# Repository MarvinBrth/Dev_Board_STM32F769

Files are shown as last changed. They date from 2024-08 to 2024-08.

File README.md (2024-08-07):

# Dev_Board_STM32F769
## Feature
- STM32F769BIT6
- OTG USB C FS
- OTG USB C HS
- DRAM
- DSI_Interface
- EMMC
### Infos
- Created with Kicad
- 6 Layer
- 5 x 5 cm
- Manufactorer: JLCPCB
- PCBA
  
## Blockdiagramm:



## Supply:



## STM32F769BIT6:



## USB_C_FS_OTG:



## USB_C_HS_OTG:



## EMMC:



## DSI_Interface:



## SDRAM:



## Layout:



## 3D-Model:



## Real life

dev_board

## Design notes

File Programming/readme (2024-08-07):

Can be programmed via the Tag-Connector using the STM32CubeIDE.
https://www.st.com/en/development-tools/stm32cubeide.html

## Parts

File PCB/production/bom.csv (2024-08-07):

Designator | Footprint | Quantity | Value | LCSC Part #
C1, C2, C35, C37, C44, C49 | 0603 | 6 | 1uF
C10 | 0805 | 1 | 22uF
C11, C12, C3, C4, C7, C8 | 0805 | 6 | 4.7uF
C13, C14, C15, C16, C17, C18, C19, C20, C21, C22, C23, C24, C25, C26, C27, C28, C30, C31, C34, C36, C41, C46, C47, C50, C51, C54, C56, C59, C61, C64, C66, C68, C69, C70, C71, C72, C74, C75, C76 | 0402 | 39 | 100nF
C29, C32, C33, C67 | 0603 | 4 | 4.7uF
C38, C42, C43, C73, C77 | 0603 | 5 | 2.2uF
C39, C40, C57, C58 | 0402 | 4 | 10pF
C45, C55 | 0603 | 2 | 5.6uF
C48, C60 | 0805 | 2 | 100uF
C5, C6, C9 | 0805 | 3 | 10uF
C52 | 0402 | 1 | 2.2uF
C53, C62, C65 | 0402 | 3 | 4.7uF
C63 | 0402 | 1 | 1uF
D1, D2, D3 | BAT165 | 3 | BAT165
D4, D5, D6, D7, D8, D9 | 0603 | 6 | LED
FB1, FB2, FB3, FB4 | 0603 | 4 | FerriteBead
J1 | JST_XH_B2B-XH-A_1x02_P2.50mm_Vertical | 1 | Conn_01x02
J3, J4 | GT-USB-7047B_JLCPCB | 2 | USB_C_Receptacle_USB2.0_16P
J5 | TE_1-84952-5_1x15-1MP_P1.0mm_Horizontal | 1 | Conn_01x15
R1, R13, R15, R2, R22, R24, R25, R3 | 0402 | 8 | 10kR
R10, R16 | 0402 | 2 | 3k3R
R11, R17 | 0402 | 2 | 430kR
R12, R18 | 0402 | 2 | 620kR
R14, R23 | 0402 | 2 | 900kR
R19 | 0402 | 1 | 20kR
R20 | 0402 | 1 | 1MR
R21 | 0402 | 1 | 8.06kR 1%
R26, R27 | Widerstandsarray_1 | 2 | 10kR
R28, R29 | 0402 | 2 | 1.5kR
R4 | 0402 | 1 | 5kR
R5, R8 | 0402 | 2 | 330R
R6, R7, R9 | 0402 | 3 | 1kR
U1 | SOT-23 | 1 | MCP1700x-180xxTT
U10, U6 | SOT-23-6 | 2 | USBLC6-2SC6
U11, U7 | TUSB321RWBR | 2 | TUSB321RWBR
U12 | EMMC | 1 | EMMC64G-IY29-5B101
U13 | TSOP-II-54_22.2x10.16mm_P0.8mm | 1 | IS42S16400J-7TL
U2 | SOT-223-3_TabPin2 | 1 | AMS1117-5.0
U3 | SOT-223-3_TabPin2 | 1 | AMS1117-3.3
U4 | LQFP-208_28x28mm_P0.5mm | 1 | STM32F769BIT6
U5, U8 | STMPS | 2 | STMPS2151STR
U9 | USB_ULPI | 1 | USB3320C-EZK-TR
Y1 | XTAL_ECS-240-10-36-CKM-TR | 1 | 26MHz
Y2 | XTAL_ECS-240-10-36-CKM-TR | 1 | 24MHz

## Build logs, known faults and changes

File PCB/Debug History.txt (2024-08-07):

18.05.24:
1. 9V to GND	/	5V to GND	/	3V3 to GND	/ 	1V8 to GND;
		Kein Kurzschluss

2. 9V angeschlossen und diverse Spannungen gechecked;
		PASS

3. Spannungen über LED´s gemessen;
		*Ist = 2,6V, Soll = 2,6V*
	
4. _test_

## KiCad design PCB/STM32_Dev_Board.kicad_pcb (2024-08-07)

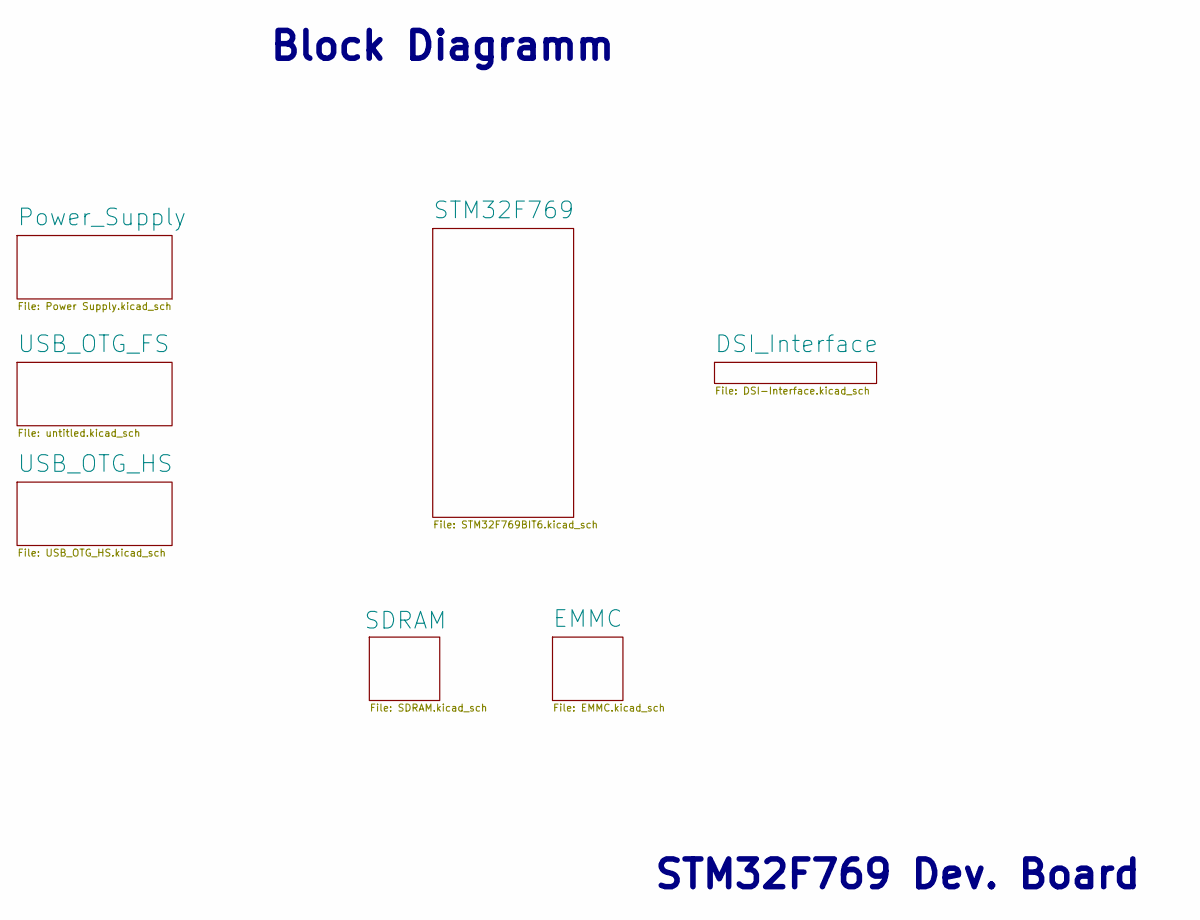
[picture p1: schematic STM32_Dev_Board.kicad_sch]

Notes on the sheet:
STM32F769 Dev. Board
Block Diagramm

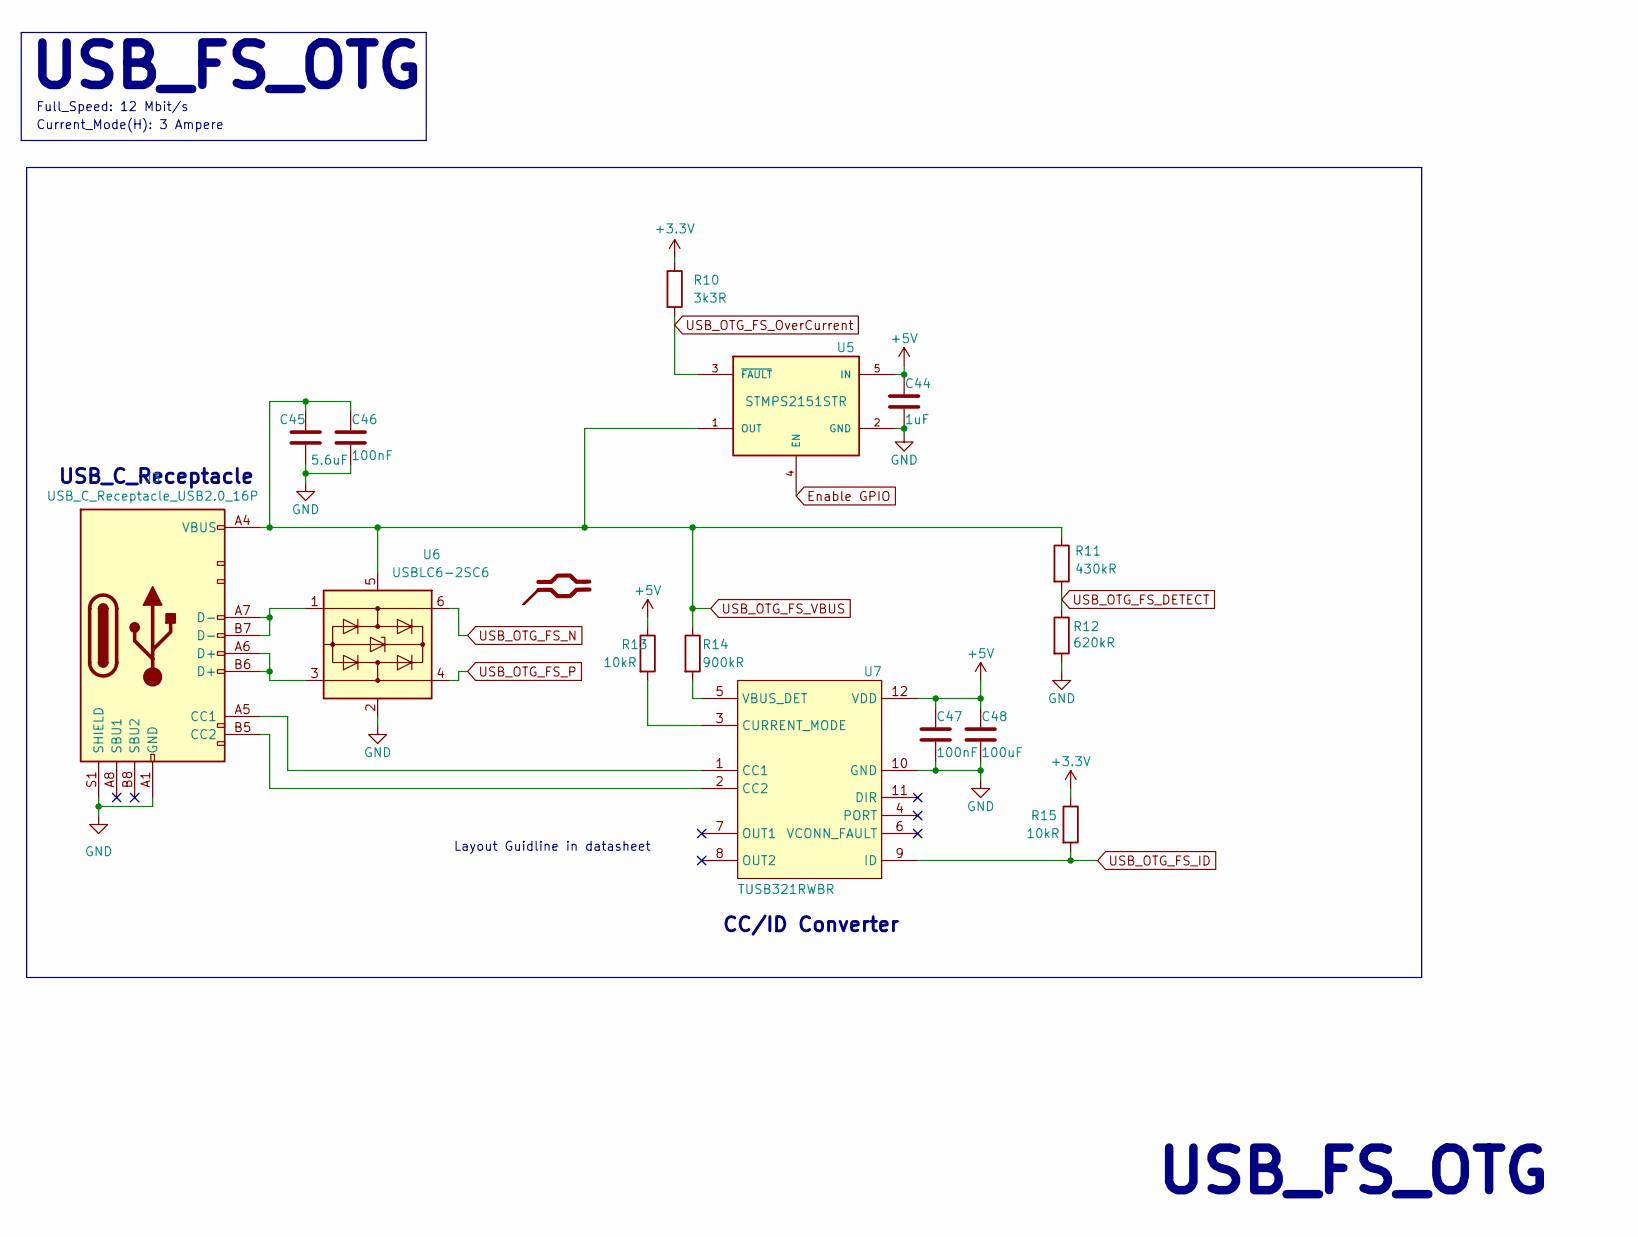
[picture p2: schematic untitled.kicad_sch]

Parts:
C44: 1uF; C_0603_1608Metric
C45: 5.6uF; C_0603_1608Metric
C46, C47: 100nF; C_0402_1005Metric
C48: 100uF; C_0805_2012Metric
J3: USB_C_Receptacle_USB2.0_16P; GT-USB-7047B_JLCPCB
R10: 3k3R; R_0402_1005Metric
R11: 430kR; R_0402_1005Metric
R12: 620kR; R_0402_1005Metric
R13, R15: 10kR; R_0402_1005Metric
R14: 900kR; R_0402_1005Metric
U5: STMPS2151STR; STMPS; PARTREV 7
U6: USBLC6-2SC6; SOT-23-6
U7: TUSB321RWBR

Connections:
+5V: C44.1, C47.1, C48.1, R13.1, U5.5 (IN), U7.12 (VDD); also elsewhere on the board
Enable GPIO: U5.4 (EN); also elsewhere on the board
GND: C44.2, C45.2, C46.2, C47.2, C48.2, J3.A1 (GND), J3.A12 (GND), J3.B1 (GND), J3.B12 (GND), J3.S1 (SHIELD), R12.2, U5.2 (GND), U6.2 (GND), U7.10 (GND); also elsewhere on the board
unnamed: J3.A5 (CC1), U7.1 (CC1)
unnamed: J3.B5 (CC2), U7.2 (CC2)
unnamed: J3.A6 (D+), J3.B6 (D+), U6.3 (I/O2)
unnamed: J3.A7 (D-), J3.B7 (D-), U6.1 (I/O1)
unnamed: R13.2, U7.3 (CURRENT_MODE)
unnamed: R14.2, U7.5 (VBUS_DET)
USB_OTG_FS_DETECT: R11.2, R12.1; also elsewhere on the board
USB_OTG_FS_ID: R15.2, U7.9 (ID); also elsewhere on the board
USB_OTG_FS_N: U6.6 (I/O1); also elsewhere on the board
USB_OTG_FS_OverCurrent: R10.2, U5.3 (~FAULT); also elsewhere on the board
USB_OTG_FS_P: U6.4 (I/O2); also elsewhere on the board
USB_OTG_FS_VBUS: C45.1, C46.1, J3.A4 (VBUS), J3.A9 (VBUS), J3.B4 (VBUS), J3.B9 (VBUS), R11.1, R14.1, U5.1 (OUT), U6.5 (VBUS); also elsewhere on the board
VDDSDMMC_STM32: R10.1, R15.1; also elsewhere on the board

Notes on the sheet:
Full_Speed: 12 Mbit/s
USB_FS_OTG
CC/ID Converter
Current_Mode(H): 3 Ampere
USB_C_Receptacle
Layout Guidline in datasheet

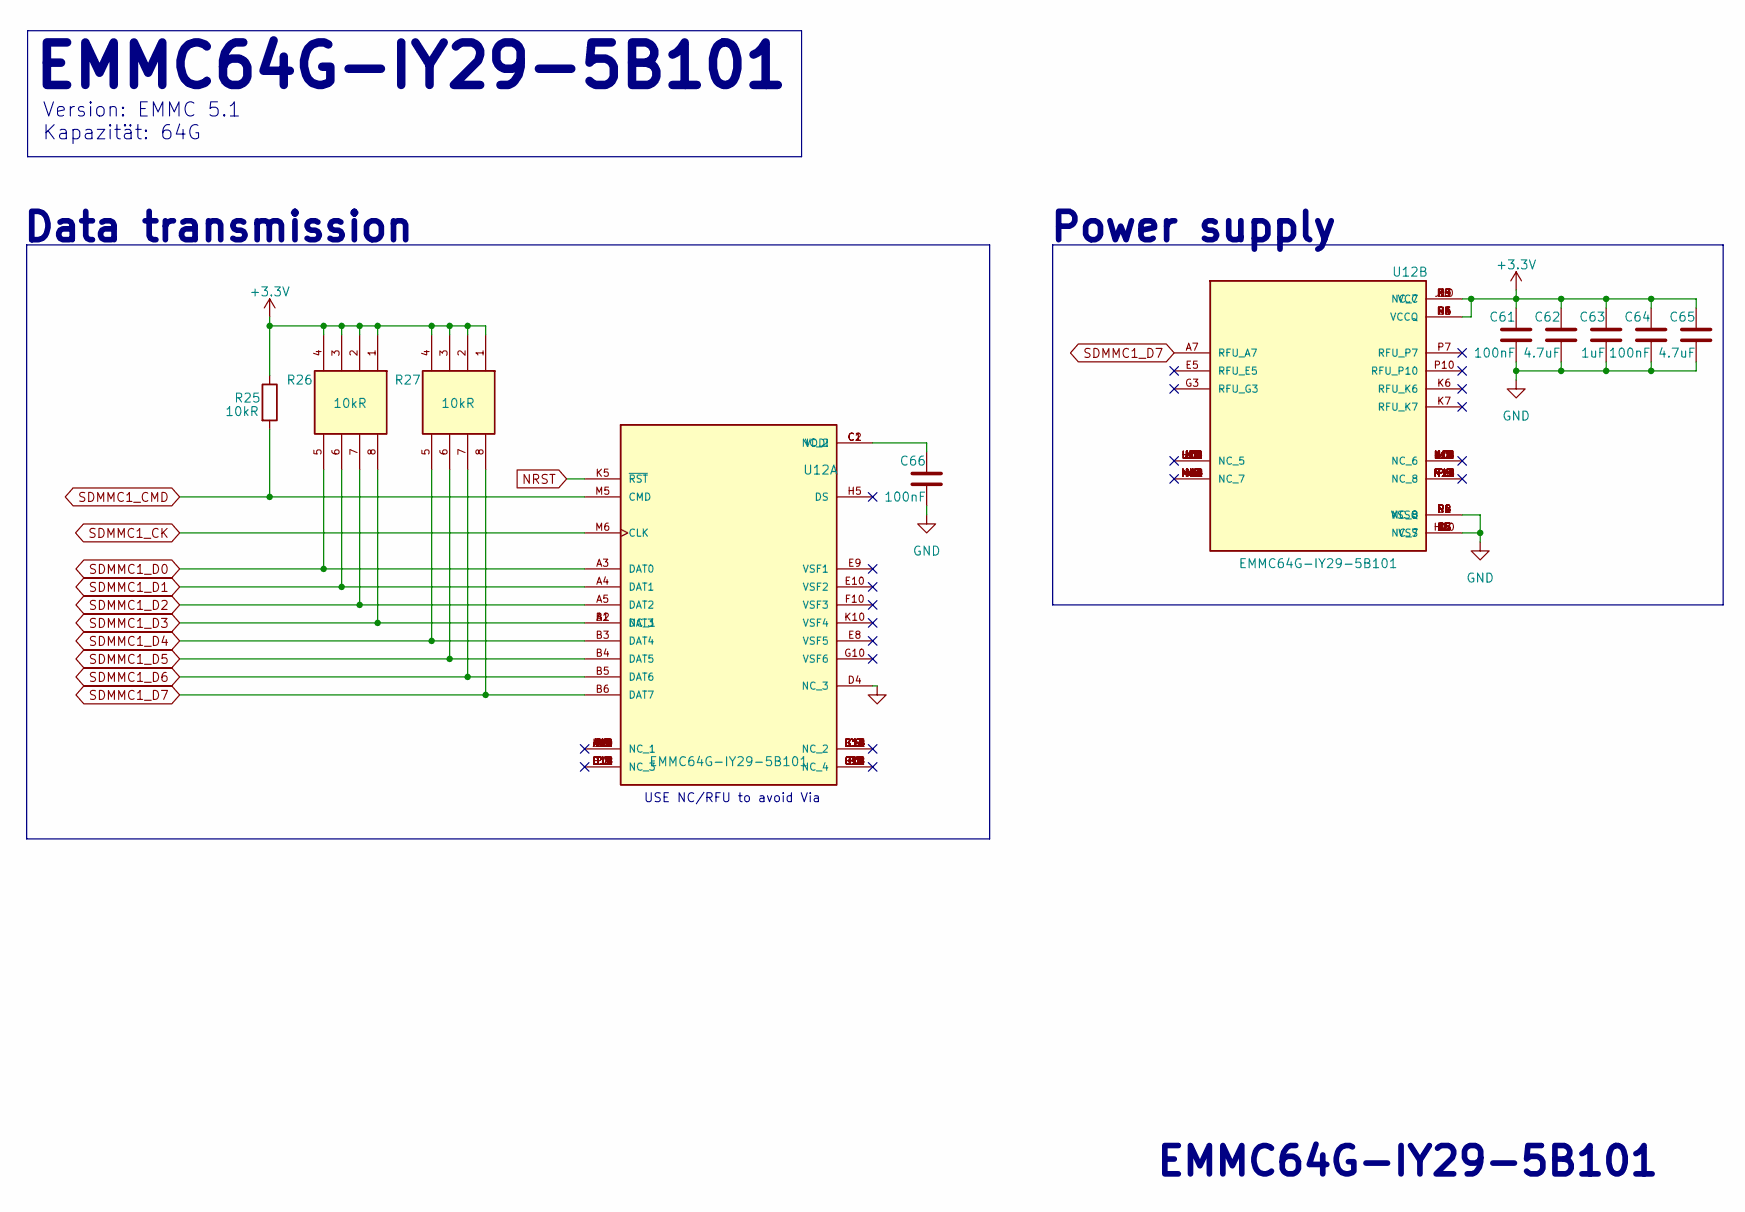
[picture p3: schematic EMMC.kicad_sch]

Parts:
C61, C64, C66: 100nF; C_0402_1005Metric
C62, C65: 4.7uF; C_0402_1005Metric
C63: 1uF; C_0402_1005Metric
R25: 10kR; R_0402_1005Metric
R26, R27: 10kR; Widerstandsarray_1; PARTREV 1-Mar-20
U12: EMMC64G-IY29-5B101; EMMC; PARTREV N/A

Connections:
GND: C61.2, C62.2, C63.2, C64.2, C65.2, C66.2, U12.A6 (VSS), U12.C4 (VSSQ), U12.D4 (NC_3), U12.E7 (VSS), U12.G5 (VSS), U12.H10 (VSS), U12.J5 (VSS), U12.K8 (VSS), U12.N2 (VSSQ), U12.N5 (VSSQ), U12.N6 (NC_7), U12.P2 (NC_8), U12.P4 (VSSQ), U12.P6 (VSSQ); also elsewhere on the board
NRST: U12.K5 (~RST); also elsewhere on the board
unnamed: C66.1, U12.C1 (NC_2), U12.C2 (VDDI)
SDMMC1_CK: U12.M6 (CLK); also elsewhere on the board
SDMMC1_CMD: R25.2, U12.M5 (CMD); also elsewhere on the board
SDMMC1_D0: R26.5, U12.A3 (DAT0); also elsewhere on the board
SDMMC1_D1: R26.6, U12.A4 (DAT1); also elsewhere on the board
SDMMC1_D2: R26.7, U12.A5 (DAT2); also elsewhere on the board
SDMMC1_D3: R26.8, U12.A1 (NC_1), U12.B2 (DAT3); also elsewhere on the board
SDMMC1_D4: R27.5, U12.A2 (NC_1), U12.B3 (DAT4); also elsewhere on the board
SDMMC1_D5: R27.6, U12.B4 (DAT5), U12.C3 (NC_2), U12.D1 (NC_3), U12.D2 (NC_3), U12.D3 (NC_3); also elsewhere on the board
SDMMC1_D6: R27.7, U12.B5 (DAT6), U12.C5 (NC_2); also elsewhere on the board
SDMMC1_D7: R27.8, U12.A7 (RFU_A7), U12.B6 (DAT7); also elsewhere on the board
VDDSDMMC_STM32: C61.1, C62.1, C63.1, C64.1, C65.1, R25.1, R26.1, R26.2, R26.3, R26.4, R27.1, R27.2, R27.3, R27.4, U12.C6 (VCCQ), U12.E6 (VCC), U12.F5 (VCC), U12.J10 (VCC), U12.K9 (VCC), U12.M4 (VCCQ), U12.N3 (NC_7), U12.N4 (VCCQ), U12.P3 (VCCQ), U12.P5 (VCCQ); also elsewhere on the board

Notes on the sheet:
USE NC/RFU to avoid Via
Data transmission
EMMC64G-IY29-5B101
Version: EMMC 5.1 Kapazität: 64G
Power supply

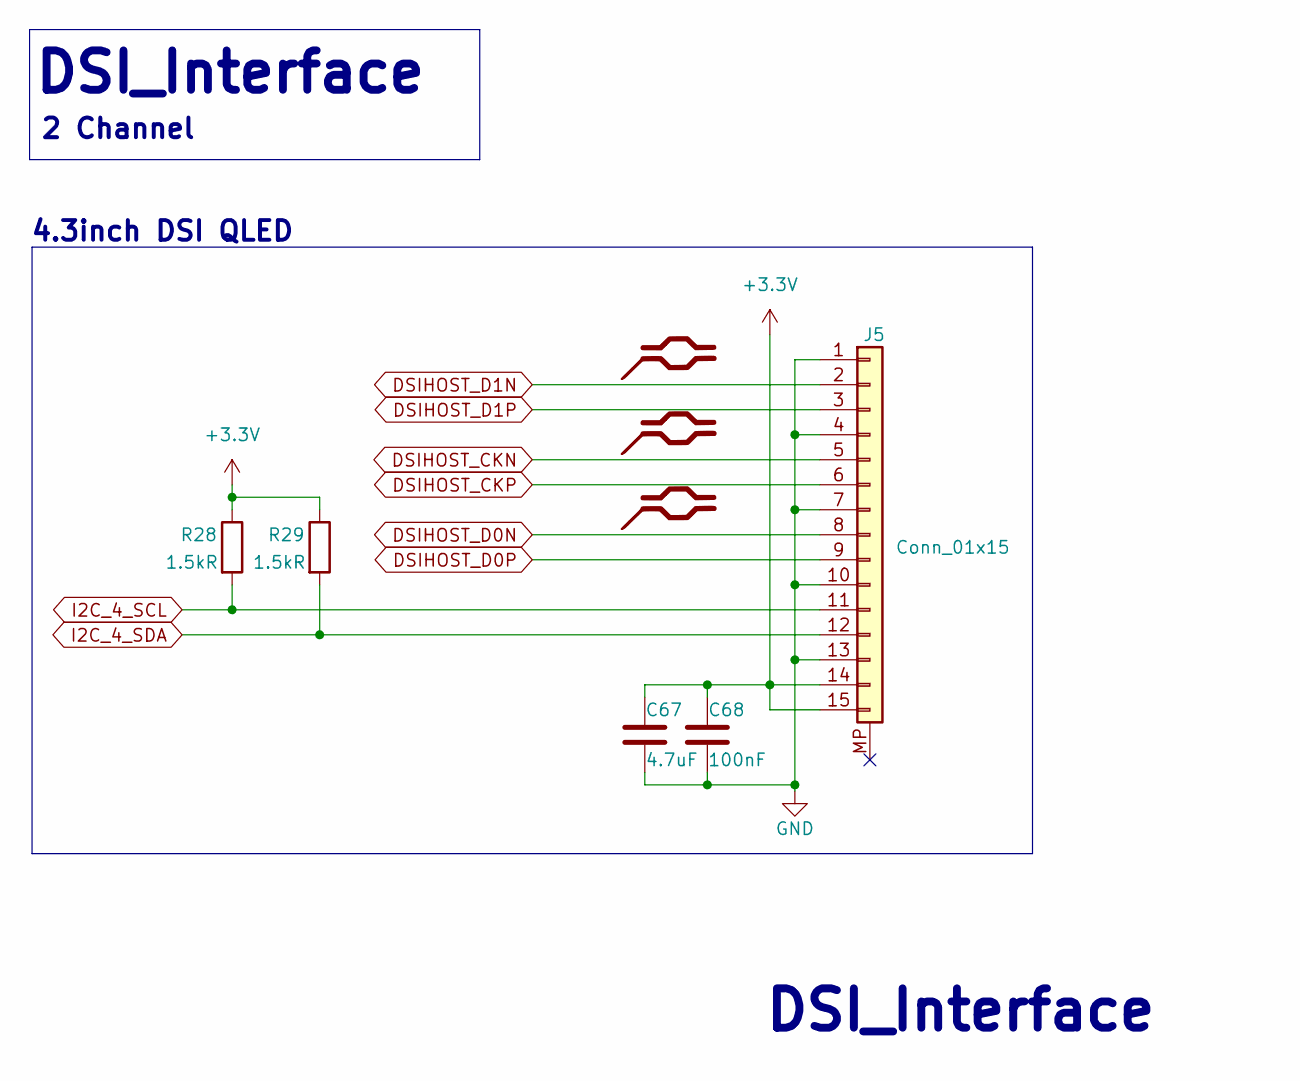
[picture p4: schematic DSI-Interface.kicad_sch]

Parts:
C67: 4.7uF; C_0603_1608Metric
C68: 100nF; C_0402_1005Metric
J5: Conn_01x15; TE_1-84952-5_1x15-1MP_P1.0mm_Horizontal
R28, R29: 1.5kR; R_0402_1005Metric

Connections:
DSIHOST_CKN: J5.5; also elsewhere on the board
DSIHOST_CKP: J5.6; also elsewhere on the board
DSIHOST_D0N: J5.8; also elsewhere on the board
DSIHOST_D0P: J5.9; also elsewhere on the board
DSIHOST_D1N: J5.2; also elsewhere on the board
DSIHOST_D1P: J5.3; also elsewhere on the board
GND: C67.2, C68.2, J5.1, J5.4, J5.7, J5.10, J5.13; also elsewhere on the board
I2C_4_SCL: J5.11, R28.2; also elsewhere on the board
I2C_4_SDA: J5.12, R29.2; also elsewhere on the board
VDDSDMMC_STM32: C67.1, C68.1, J5.14, J5.15, R28.1, R29.1; also elsewhere on the board

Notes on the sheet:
DSI_Interface
2 Channel
4.3inch DSI QLED

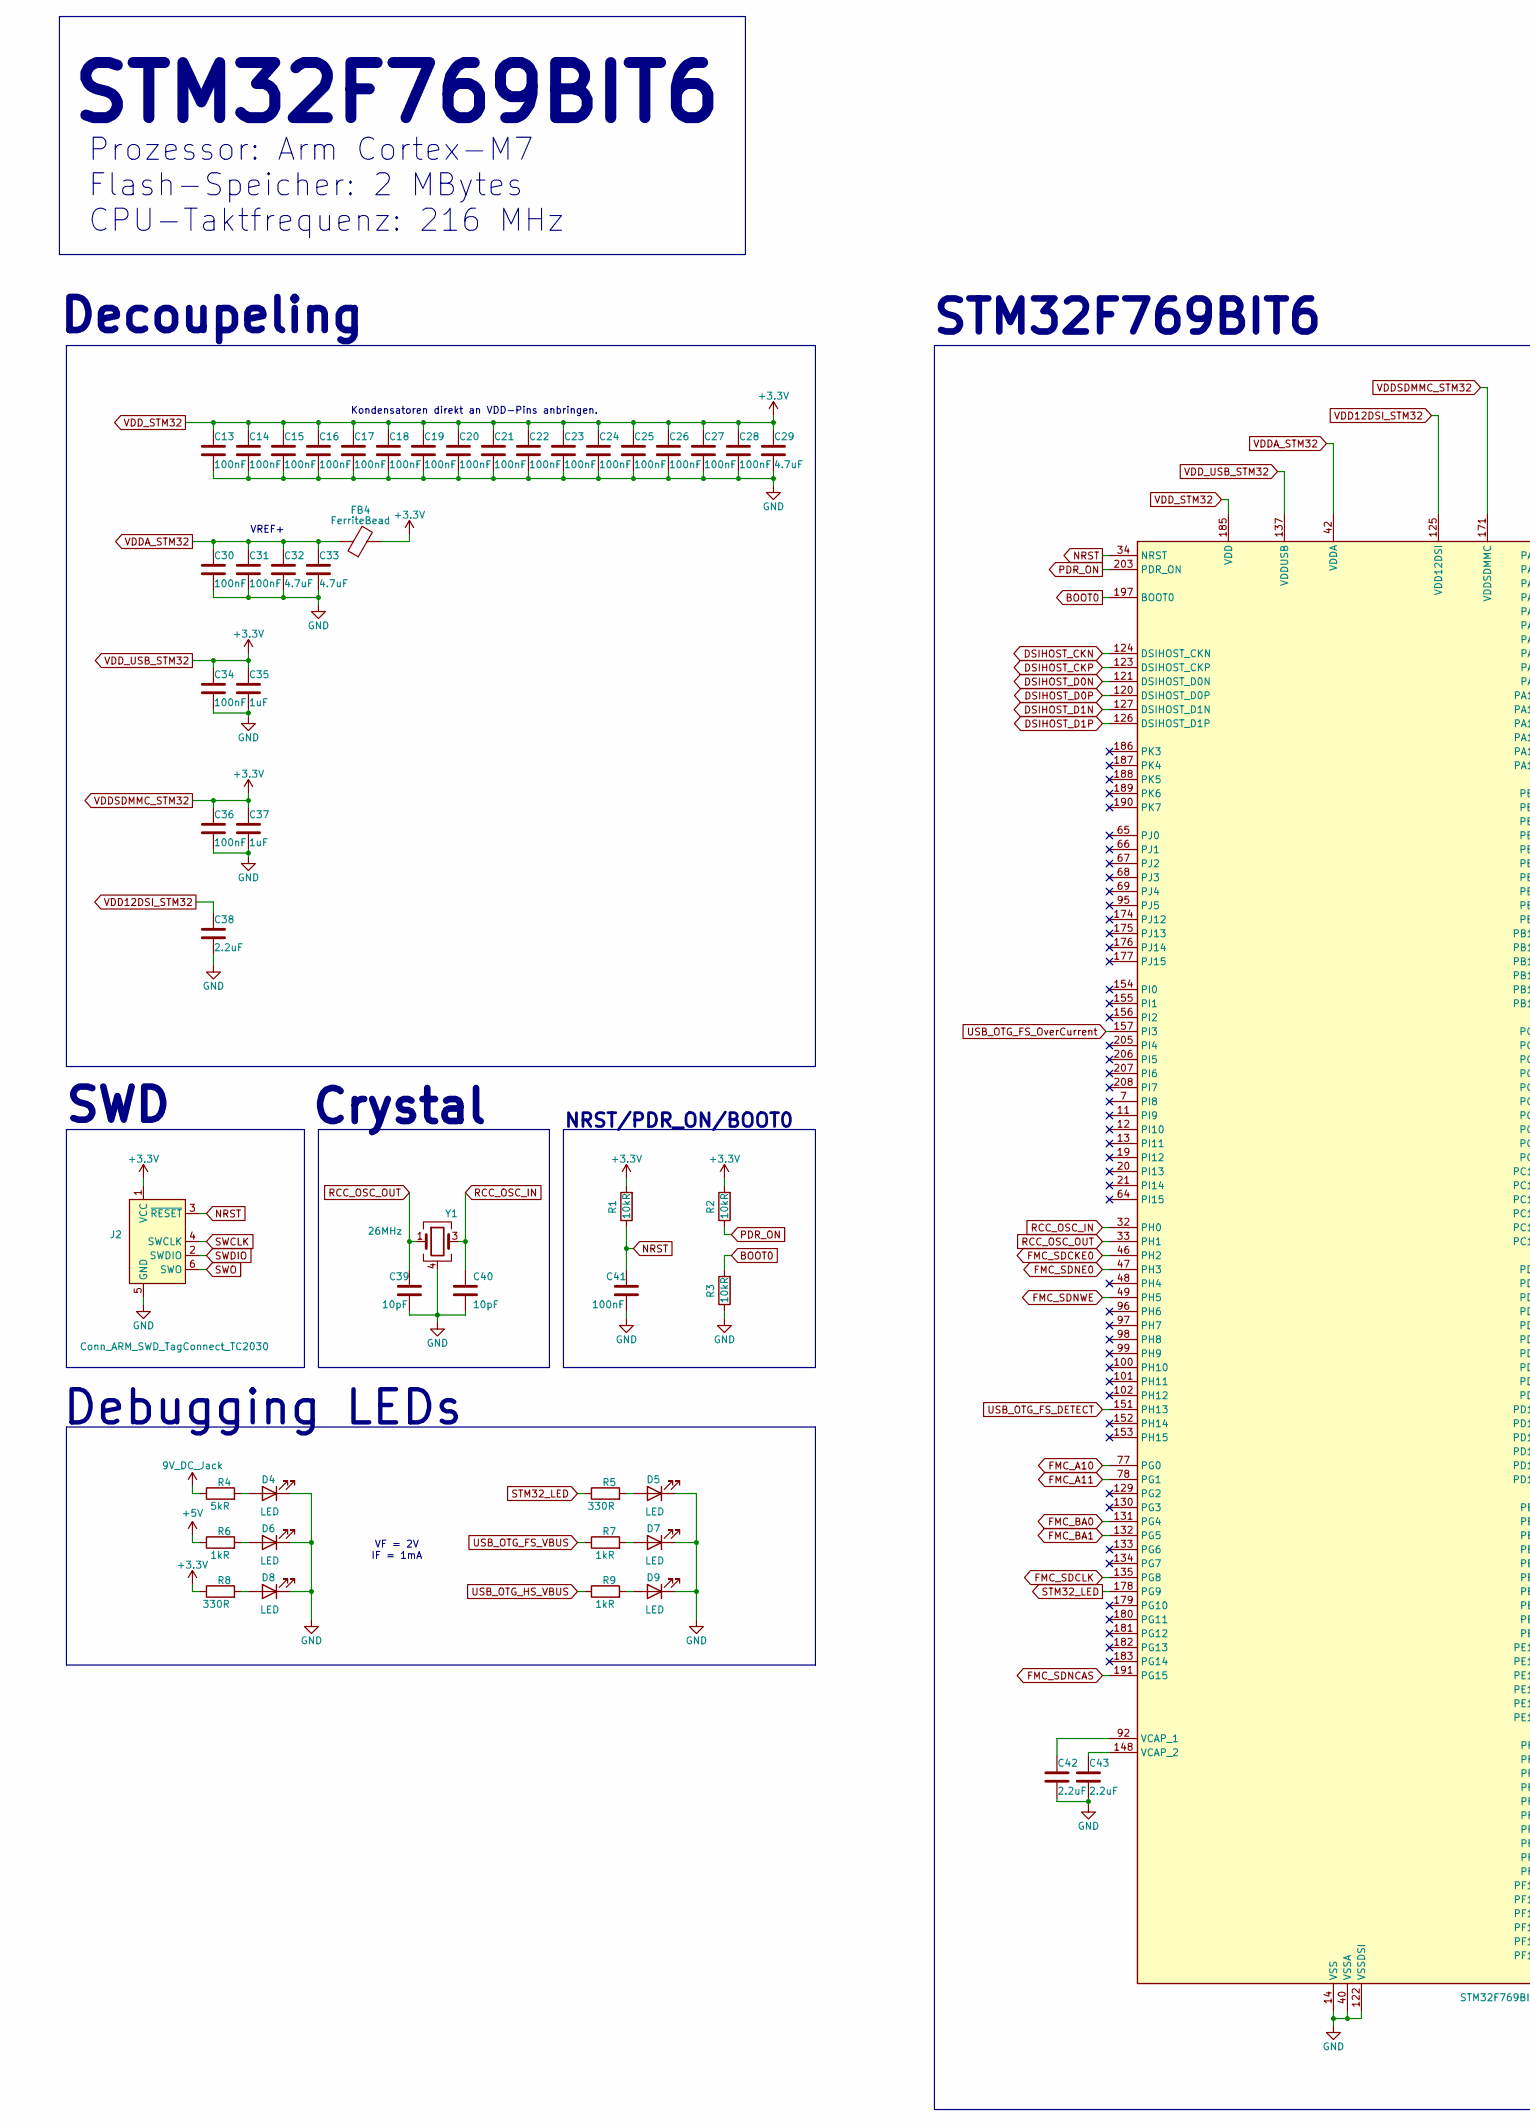
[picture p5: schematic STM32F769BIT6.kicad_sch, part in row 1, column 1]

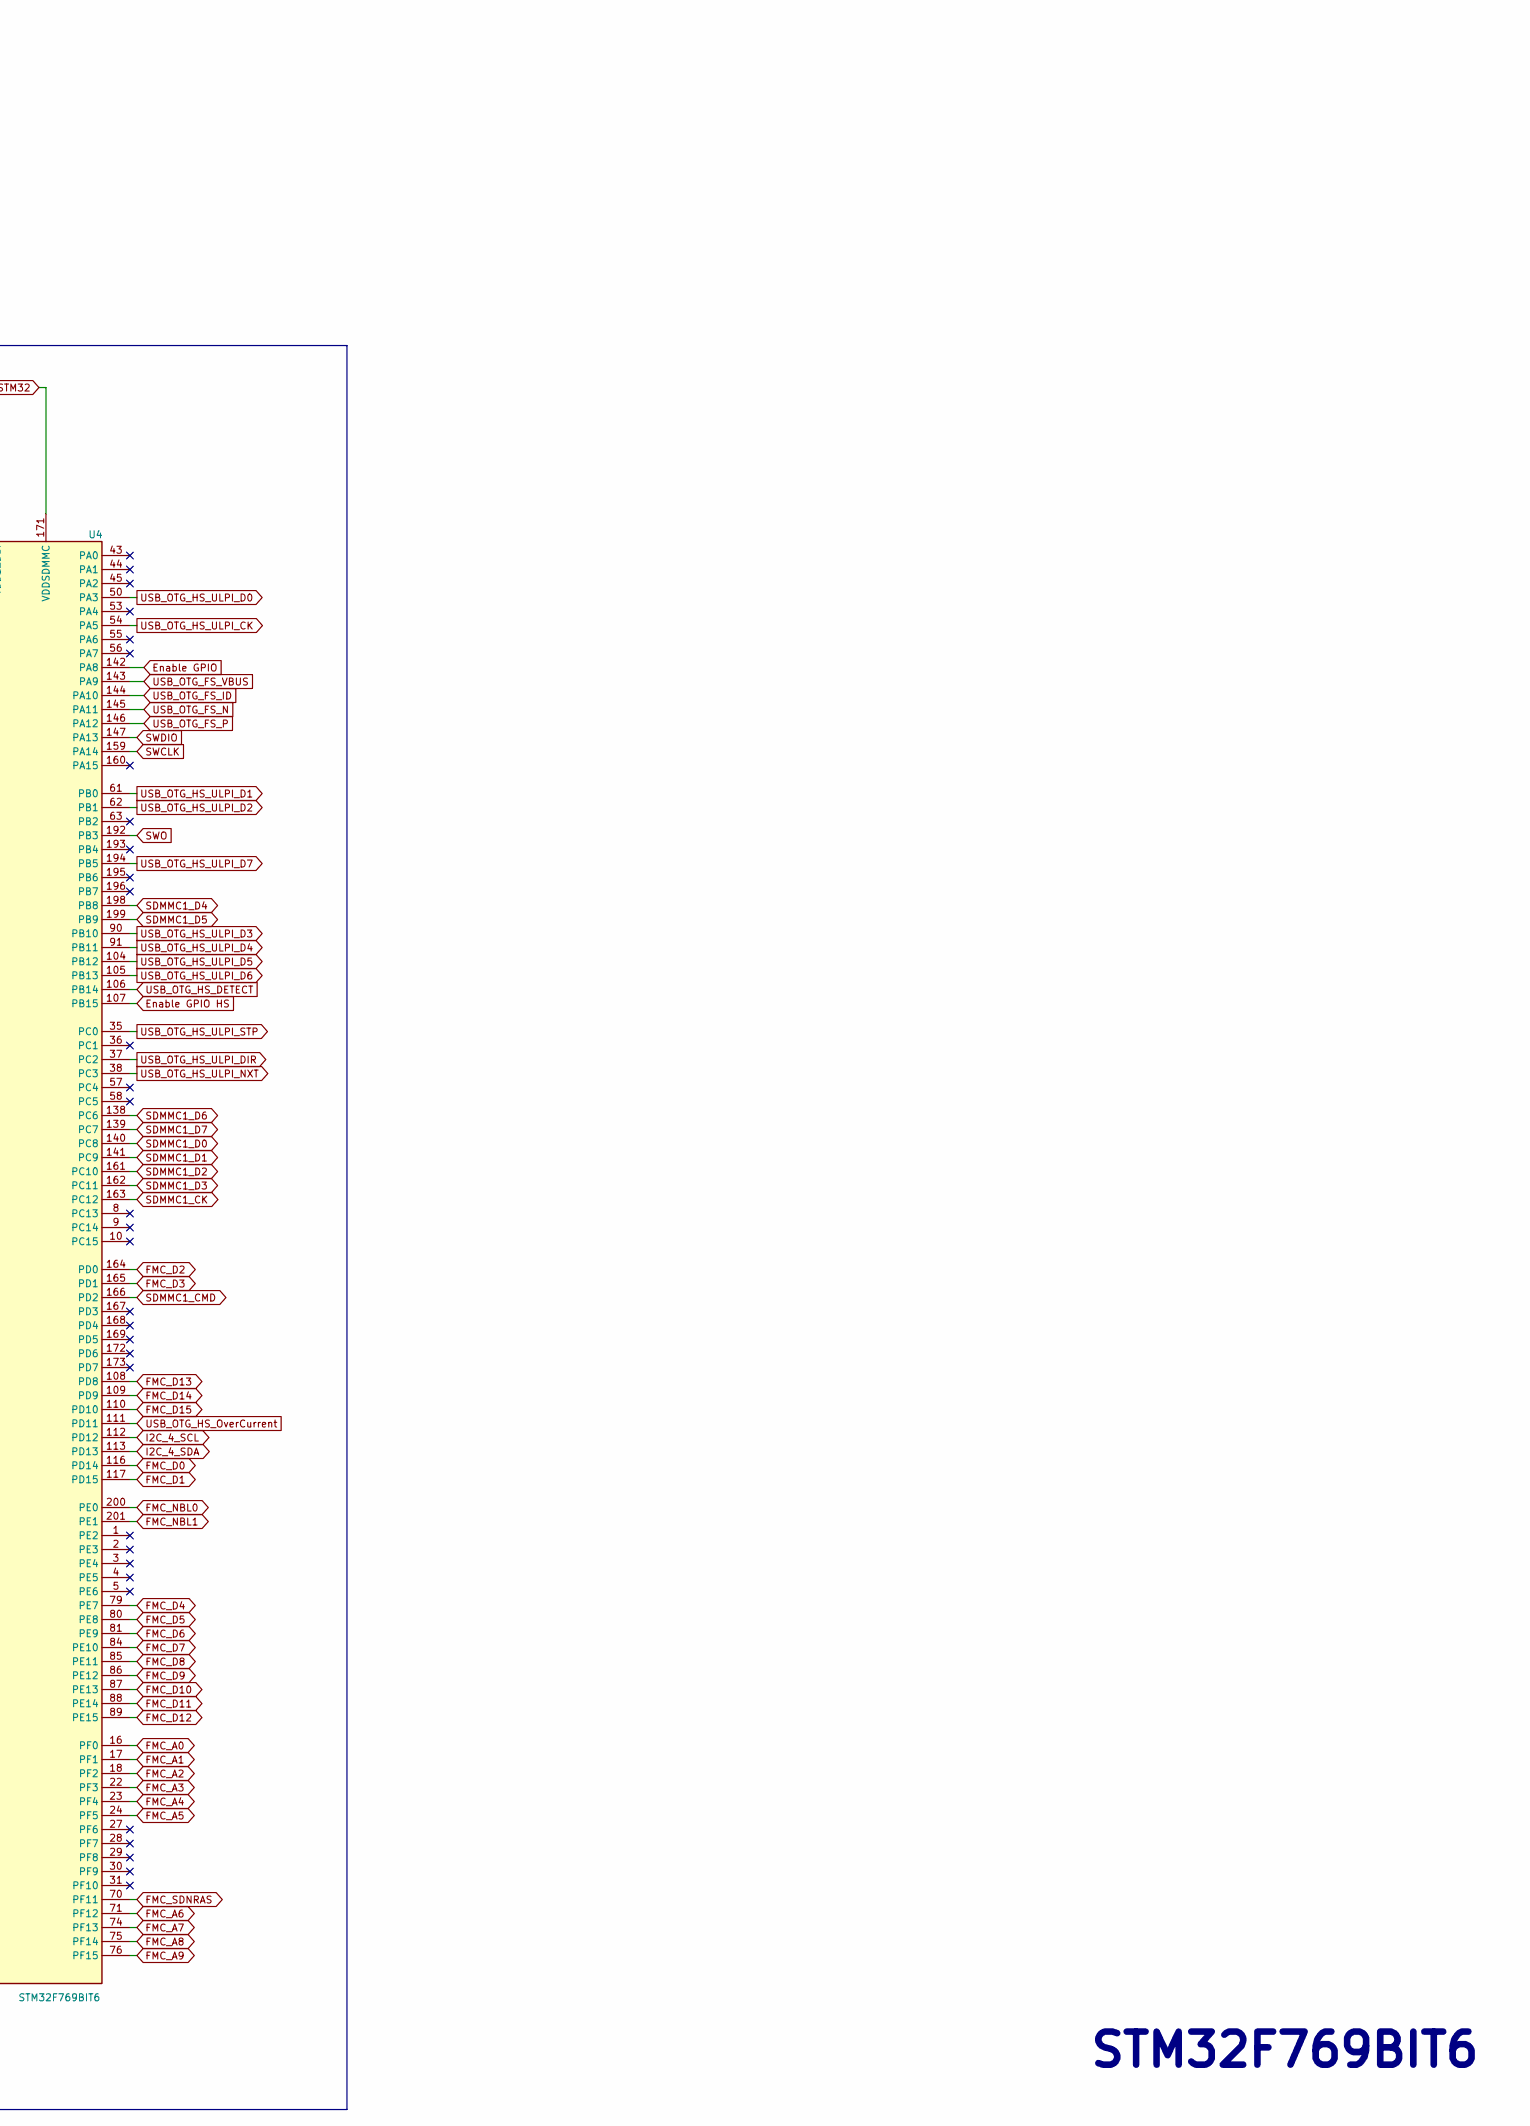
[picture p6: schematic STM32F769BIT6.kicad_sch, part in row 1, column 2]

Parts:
C13, C14, C15, C16, C17, C18, C19, C20, C21, C22, C23, C24, C25, C26, C27, C28, C30, C31, C34, C36, C41: 100nF; C_0402_1005Metric
C29, C32, C33: 4.7uF; C_0603_1608Metric
C35, C37: 1uF; C_0603_1608Metric
C38, C42, C43: 2.2uF; C_0603_1608Metric
C39, C40: 10pF; C_0402_1005Metric
D4, D5, D6, D7, D8, D9: LED; LED_0603_1608Metric
FB4: FerriteBead; L_0603_1608Metric
J2: Conn_ARM_SWD_TagConnect_TC2030; Tag-Connect_TC2030-IDC-FP_2x03_P1.27mm_Vertical
R1, R2, R3: 10kR; R_0402_1005Metric
R4: 5kR; R_0402_1005Metric
R5, R8: 330R; R_0402_1005Metric
R6, R7, R9: 1kR; R_0402_1005Metric
U4: STM32F769BIT6; LQFP-208_28x28mm_P0.5mm
Y1: 26MHz; XTAL_ECS-240-10-36-CKM-TR

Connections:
9V_DC_Jack: R4.1; also elsewhere on the board
+5V: R6.1; also elsewhere on the board
BOOT0: R3.2, U4.197 (BOOT0)
DSIHOST_CKN: U4.124 (DSIHOST_CKN); also elsewhere on the board
DSIHOST_CKP: U4.123 (DSIHOST_CKP); also elsewhere on the board
DSIHOST_D0N: U4.121 (DSIHOST_D0N); also elsewhere on the board
DSIHOST_D0P: U4.120 (DSIHOST_D0P); also elsewhere on the board
DSIHOST_D1N: U4.127 (DSIHOST_D1N); also elsewhere on the board
DSIHOST_D1P: U4.126 (DSIHOST_D1P); also elsewhere on the board
Enable GPIO: U4.142 (PA8); also elsewhere on the board
Enable GPIO HS: U4.107 (PB15); also elsewhere on the board
FMC_A0: U4.16 (PF0); also elsewhere on the board
FMC_A1: U4.17 (PF1); also elsewhere on the board
FMC_A2: U4.18 (PF2); also elsewhere on the board
FMC_A3: U4.22 (PF3); also elsewhere on the board
FMC_A4: U4.23 (PF4); also elsewhere on the board
FMC_A5: U4.24 (PF5); also elsewhere on the board
FMC_A6: U4.71 (PF12); also elsewhere on the board
FMC_A7: U4.74 (PF13); also elsewhere on the board
FMC_A8: U4.75 (PF14); also elsewhere on the board
FMC_A9: U4.76 (PF15); also elsewhere on the board
FMC_A10: U4.77 (PG0); also elsewhere on the board
FMC_A11: U4.78 (PG1); also elsewhere on the board
FMC_BA0: U4.131 (PG4); also elsewhere on the board
FMC_BA1: U4.132 (PG5); also elsewhere on the board
FMC_D0: U4.116 (PD14); also elsewhere on the board
FMC_D1: U4.117 (PD15); also elsewhere on the board
FMC_D2: U4.164 (PD0); also elsewhere on the board
FMC_D3: U4.165 (PD1); also elsewhere on the board
FMC_D4: U4.79 (PE7); also elsewhere on the board
FMC_D5: U4.80 (PE8); also elsewhere on the board
FMC_D6: U4.81 (PE9); also elsewhere on the board
FMC_D7: U4.84 (PE10); also elsewhere on the board
FMC_D8: U4.85 (PE11); also elsewhere on the board
FMC_D9: U4.86 (PE12); also elsewhere on the board
FMC_D10: U4.87 (PE13); also elsewhere on the board
FMC_D11: U4.88 (PE14); also elsewhere on the board
FMC_D12: U4.89 (PE15); also elsewhere on the board
FMC_D13: U4.108 (PD8); also elsewhere on the board
FMC_D14: U4.109 (PD9); also elsewhere on the board
FMC_D15: U4.110 (PD10); also elsewhere on the board
FMC_NBL0: U4.200 (PE0); also elsewhere on the board
FMC_NBL1: U4.201 (PE1); also elsewhere on the board
FMC_SDCKE0: U4.46 (PH2); also elsewhere on the board
FMC_SDCLK: U4.135 (PG8); also elsewhere on the board
FMC_SDNCAS: U4.191 (PG15); also elsewhere on the board
FMC_SDNE0: U4.47 (PH3); also elsewhere on the board
FMC_SDNRAS: U4.70 (PF11); also elsewhere on the board
FMC_SDNWE: U4.49 (PH5); also elsewhere on the board
GND: C13.2, C14.2, C15.2, C16.2, C17.2, C18.2, C19.2, C20.2, C21.2, C22.2, C23.2, C24.2, C25.2, C26.2, C27.2, C28.2, C29.2, C30.2, C31.2, C32.2, C33.2, C34.2, C35.2, C36.2, C37.2, C38.2, C39.2, C40.2, C41.2, C42.2, C43.2, D4.1 (K), D5.1 (K), D6.1 (K), D7.1 (K), D8.1 (K), D9.1 (K), J2.5 (GND), R3.1, U4.14 (VSS), U4.25 (VSS), U4.40 (VSSA), U4.51 (VSS), U4.60 (VSS), U4.72 (VSS), U4.82 (VSS), U4.93 (VSS), U4.114 (VSS), U4.122 (VSSDSI), U4.128 (VSSDSI), U4.136 (VSS), U4.149 (VSS), U4.170 (VSS), U4.184 (VSS), U4.202 (VSS), Y1.2, Y1.4; also elsewhere on the board
I2C_4_SCL: U4.112 (PD12); also elsewhere on the board
I2C_4_SDA: U4.113 (PD13); also elsewhere on the board
NRST: C41.1, J2.3 (~RESET), R1.1, U4.34 (NRST); also elsewhere on the board
unnamed: D4.2 (A), R4.2
unnamed: D5.2 (A), R5.2
unnamed: D6.2 (A), R6.2
unnamed: D7.2 (A), R7.2
unnamed: D8.2 (A), R8.2
unnamed: D9.2 (A), R9.2
unnamed: C42.1, U4.92 (VCAP_1)
unnamed: C43.1, U4.148 (VCAP_2)
PDR_ON: R2.1, U4.203 (PDR_ON)
RCC_OSC_IN: C40.1, U4.32 (PH0), Y1.3
RCC_OSC_OUT: C39.1, U4.33 (PH1), Y1.1
SDMMC1_CK: U4.163 (PC12); also elsewhere on the board
SDMMC1_CMD: U4.166 (PD2); also elsewhere on the board
SDMMC1_D0: U4.140 (PC8); also elsewhere on the board
SDMMC1_D1: U4.141 (PC9); also elsewhere on the board
SDMMC1_D2: U4.161 (PC10); also elsewhere on the board
SDMMC1_D3: U4.162 (PC11); also elsewhere on the board
SDMMC1_D4: U4.198 (PB8); also elsewhere on the board
SDMMC1_D5: U4.199 (PB9); also elsewhere on the board
SDMMC1_D6: U4.138 (PC6); also elsewhere on the board
SDMMC1_D7: U4.139 (PC7); also elsewhere on the board
STM32_LED: R5.1, U4.178 (PG9)
SWCLK: J2.4 (SWCLK), U4.159 (PA14)
SWDIO: J2.2 (SWDIO), U4.147 (PA13)
SWO: J2.6 (SWO), U4.192 (PB3)
USB_OTG_FS_DETECT: U4.151 (PH13); also elsewhere on the board
USB_OTG_FS_ID: U4.144 (PA10); also elsewhere on the board
USB_OTG_FS_N: U4.145 (PA11); also elsewhere on the board
USB_OTG_FS_OverCurrent: U4.157 (PI3); also elsewhere on the board
USB_OTG_FS_P: U4.146 (PA12); also elsewhere on the board
USB_OTG_FS_VBUS: R7.1, U4.143 (PA9); also elsewhere on the board
USB_OTG_HS_DETECT: U4.106 (PB14); also elsewhere on the board
USB_OTG_HS_OverCurrent: U4.111 (PD11); also elsewhere on the board
USB_OTG_HS_ULPI_CK: U4.54 (PA5); also elsewhere on the board
USB_OTG_HS_ULPI_D0: U4.50 (PA3); also elsewhere on the board
USB_OTG_HS_ULPI_D1: U4.61 (PB0); also elsewhere on the board
USB_OTG_HS_ULPI_D2: U4.62 (PB1); also elsewhere on the board
USB_OTG_HS_ULPI_D3: U4.90 (PB10); also elsewhere on the board
USB_OTG_HS_ULPI_D4: U4.91 (PB11); also elsewhere on the board
USB_OTG_HS_ULPI_D5: U4.104 (PB12); also elsewhere on the board
USB_OTG_HS_ULPI_D6: U4.105 (PB13); also elsewhere on the board
USB_OTG_HS_ULPI_D7: U4.194 (PB5); also elsewhere on the board
USB_OTG_HS_ULPI_DIR: U4.37 (PC2); also elsewhere on the board
USB_OTG_HS_ULPI_NXT: U4.38 (PC3); also elsewhere on the board
USB_OTG_HS_ULPI_STP: U4.35 (PC0); also elsewhere on the board
USB_OTG_HS_VBUS: R9.1; also elsewhere on the board
VDD12DSI_STM32: C38.1, U4.119 (VCAPDSI), U4.125 (VDD12DSI)
VDDA_STM32: C30.1, C31.1, C32.1, C33.1, FB4.1, U4.41 (VREF+), U4.42 (VDDA)
VDDSDMMC_STM32: C13.1, C14.1, C15.1, C16.1, C17.1, C18.1, C19.1, C20.1, C21.1, C22.1, C23.1, C24.1, C25.1, C26.1, C27.1, C28.1, C29.1, C34.1, C35.1, C36.1, C37.1, FB4.2, J2.1 (VCC), R1.2, R2.2, R8.1, U4.6 (VBAT), U4.15 (VDD), U4.26 (VDD), U4.39 (VDD), U4.52 (VDD), U4.59 (VDD), U4.73 (VDD), U4.83 (VDD), U4.94 (VDD), U4.103 (VDD), U4.115 (VDD), U4.118 (VDDDSI), U4.137 (VDDUSB), U4.150 (VDD), U4.158 (VDD), U4.171 (VDDSDMMC), U4.185 (VDD), U4.204 (VDD); also elsewhere on the board

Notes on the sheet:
STM32F769BIT6
Decoupeling
STM32F769BIT6
Debugging LEDs
VF = 2V IF = 1mA
SWD
Kondensatoren direkt an VDD-Pins anbringen.
Crystal
NRST/PDR_ON/BOOT0
Prozessor: Arm Cortex-M7 Flash-Speicher: 2 MBytes CPU-Taktfrequenz: 216 MHz
VREF+

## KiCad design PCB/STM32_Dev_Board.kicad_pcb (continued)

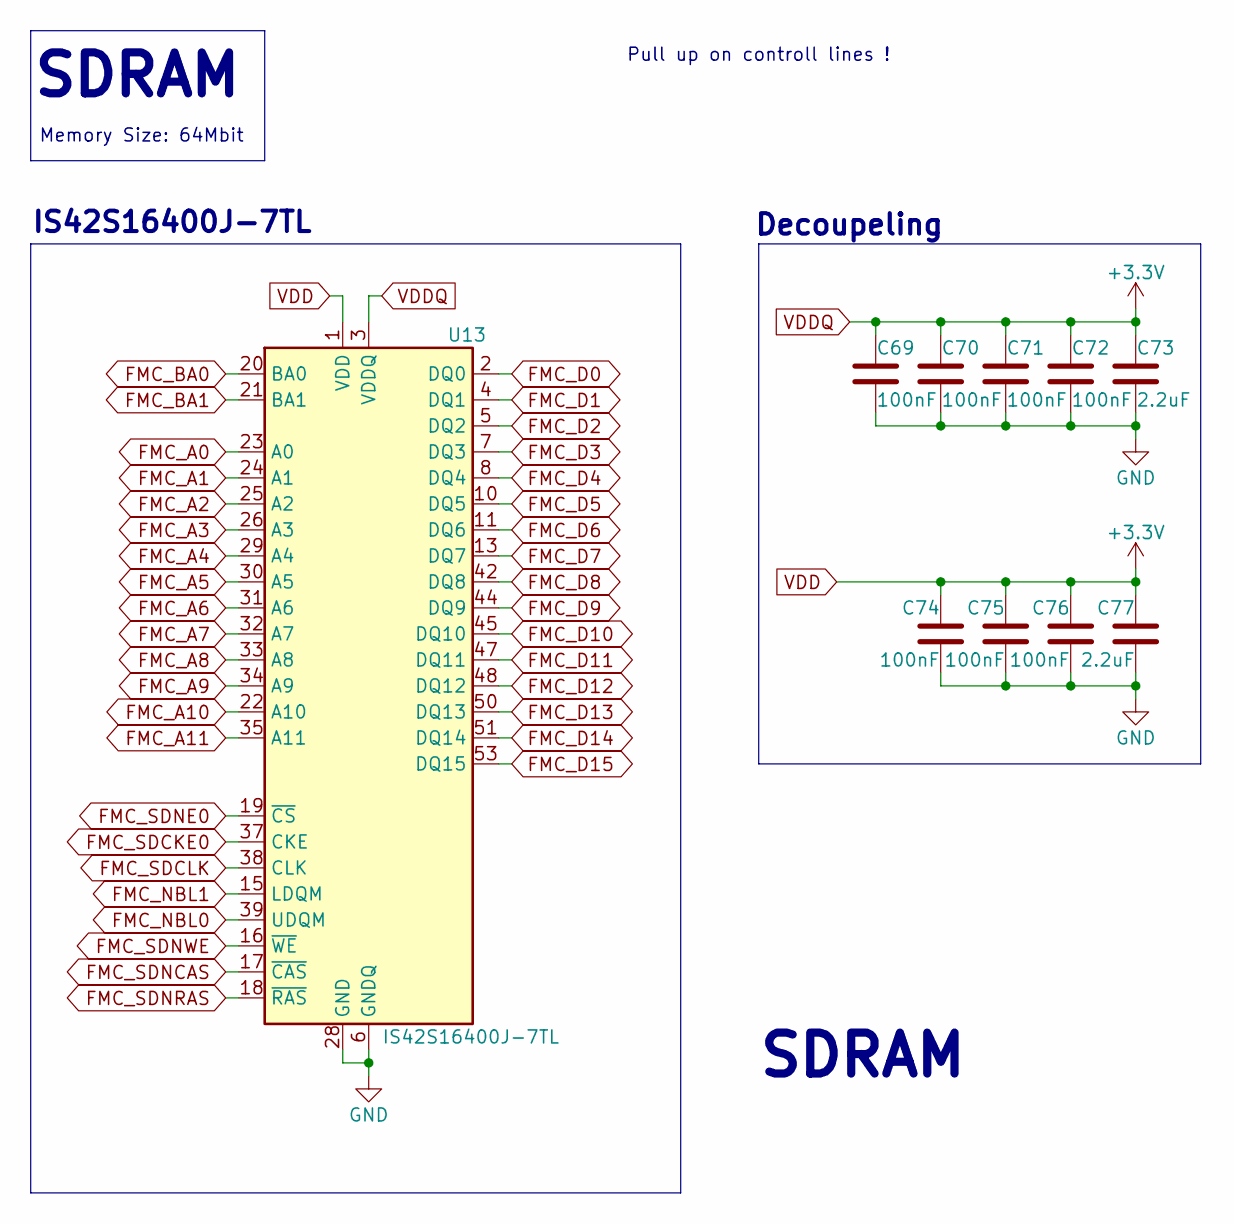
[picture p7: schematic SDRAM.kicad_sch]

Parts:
C69, C70, C71, C72, C74, C75, C76: 100nF; C_0402_1005Metric
C73, C77: 2.2uF; C_0603_1608Metric
U13: IS42S16400J-7TL; TSOP-II-54_22.2x10.16mm_P0.8mm

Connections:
FMC_A0: U13.23 (A0); also elsewhere on the board
FMC_A1: U13.24 (A1); also elsewhere on the board
FMC_A2: U13.25 (A2); also elsewhere on the board
FMC_A3: U13.26 (A3); also elsewhere on the board
FMC_A4: U13.29 (A4); also elsewhere on the board
FMC_A5: U13.30 (A5); also elsewhere on the board
FMC_A6: U13.31 (A6); also elsewhere on the board
FMC_A7: U13.32 (A7); also elsewhere on the board
FMC_A8: U13.33 (A8); also elsewhere on the board
FMC_A9: U13.34 (A9); also elsewhere on the board
FMC_A10: U13.22 (A10); also elsewhere on the board
FMC_A11: U13.35 (A11); also elsewhere on the board
FMC_BA0: U13.20 (BA0); also elsewhere on the board
FMC_BA1: U13.21 (BA1); also elsewhere on the board
FMC_D0: U13.2 (DQ0); also elsewhere on the board
FMC_D1: U13.4 (DQ1); also elsewhere on the board
FMC_D2: U13.5 (DQ2); also elsewhere on the board
FMC_D3: U13.7 (DQ3); also elsewhere on the board
FMC_D4: U13.8 (DQ4); also elsewhere on the board
FMC_D5: U13.10 (DQ5); also elsewhere on the board
FMC_D6: U13.11 (DQ6); also elsewhere on the board
FMC_D7: U13.13 (DQ7); also elsewhere on the board
FMC_D8: U13.42 (DQ8); also elsewhere on the board
FMC_D9: U13.44 (DQ9); also elsewhere on the board
FMC_D10: U13.45 (DQ10); also elsewhere on the board
FMC_D11: U13.47 (DQ11); also elsewhere on the board
FMC_D12: U13.48 (DQ12); also elsewhere on the board
FMC_D13: U13.50 (DQ13); also elsewhere on the board
FMC_D14: U13.51 (DQ14); also elsewhere on the board
FMC_D15: U13.53 (DQ15); also elsewhere on the board
FMC_NBL0: U13.39 (UDQM); also elsewhere on the board
FMC_NBL1: U13.15 (LDQM); also elsewhere on the board
FMC_SDCKE0: U13.37 (CKE); also elsewhere on the board
FMC_SDCLK: U13.38 (CLK); also elsewhere on the board
FMC_SDNCAS: U13.17 (~CAS); also elsewhere on the board
FMC_SDNE0: U13.19 (~CS); also elsewhere on the board
FMC_SDNRAS: U13.18 (~RAS); also elsewhere on the board
FMC_SDNWE: U13.16 (~WE); also elsewhere on the board
GND: C69.2, C70.2, C71.2, C72.2, C73.2, C74.2, C75.2, C76.2, C77.2, U13.6 (GNDQ), U13.12 (GNDQ), U13.28 (GND), U13.41 (GND), U13.46 (GNDQ), U13.52 (GNDQ), U13.54 (GND); also elsewhere on the board
VDDSDMMC_STM32: C69.1, C70.1, C71.1, C72.1, C73.1, C74.1, C75.1, C76.1, C77.1, U13.1 (VDD), U13.3 (VDDQ), U13.9 (VDDQ), U13.14 (VDD), U13.27 (VDD), U13.43 (VDDQ), U13.49 (VDDQ); also elsewhere on the board

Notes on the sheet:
Decoupeling
Pull up on controll lines !
Memory Size: 64Mbit
SDRAM
IS42S16400J-7TL

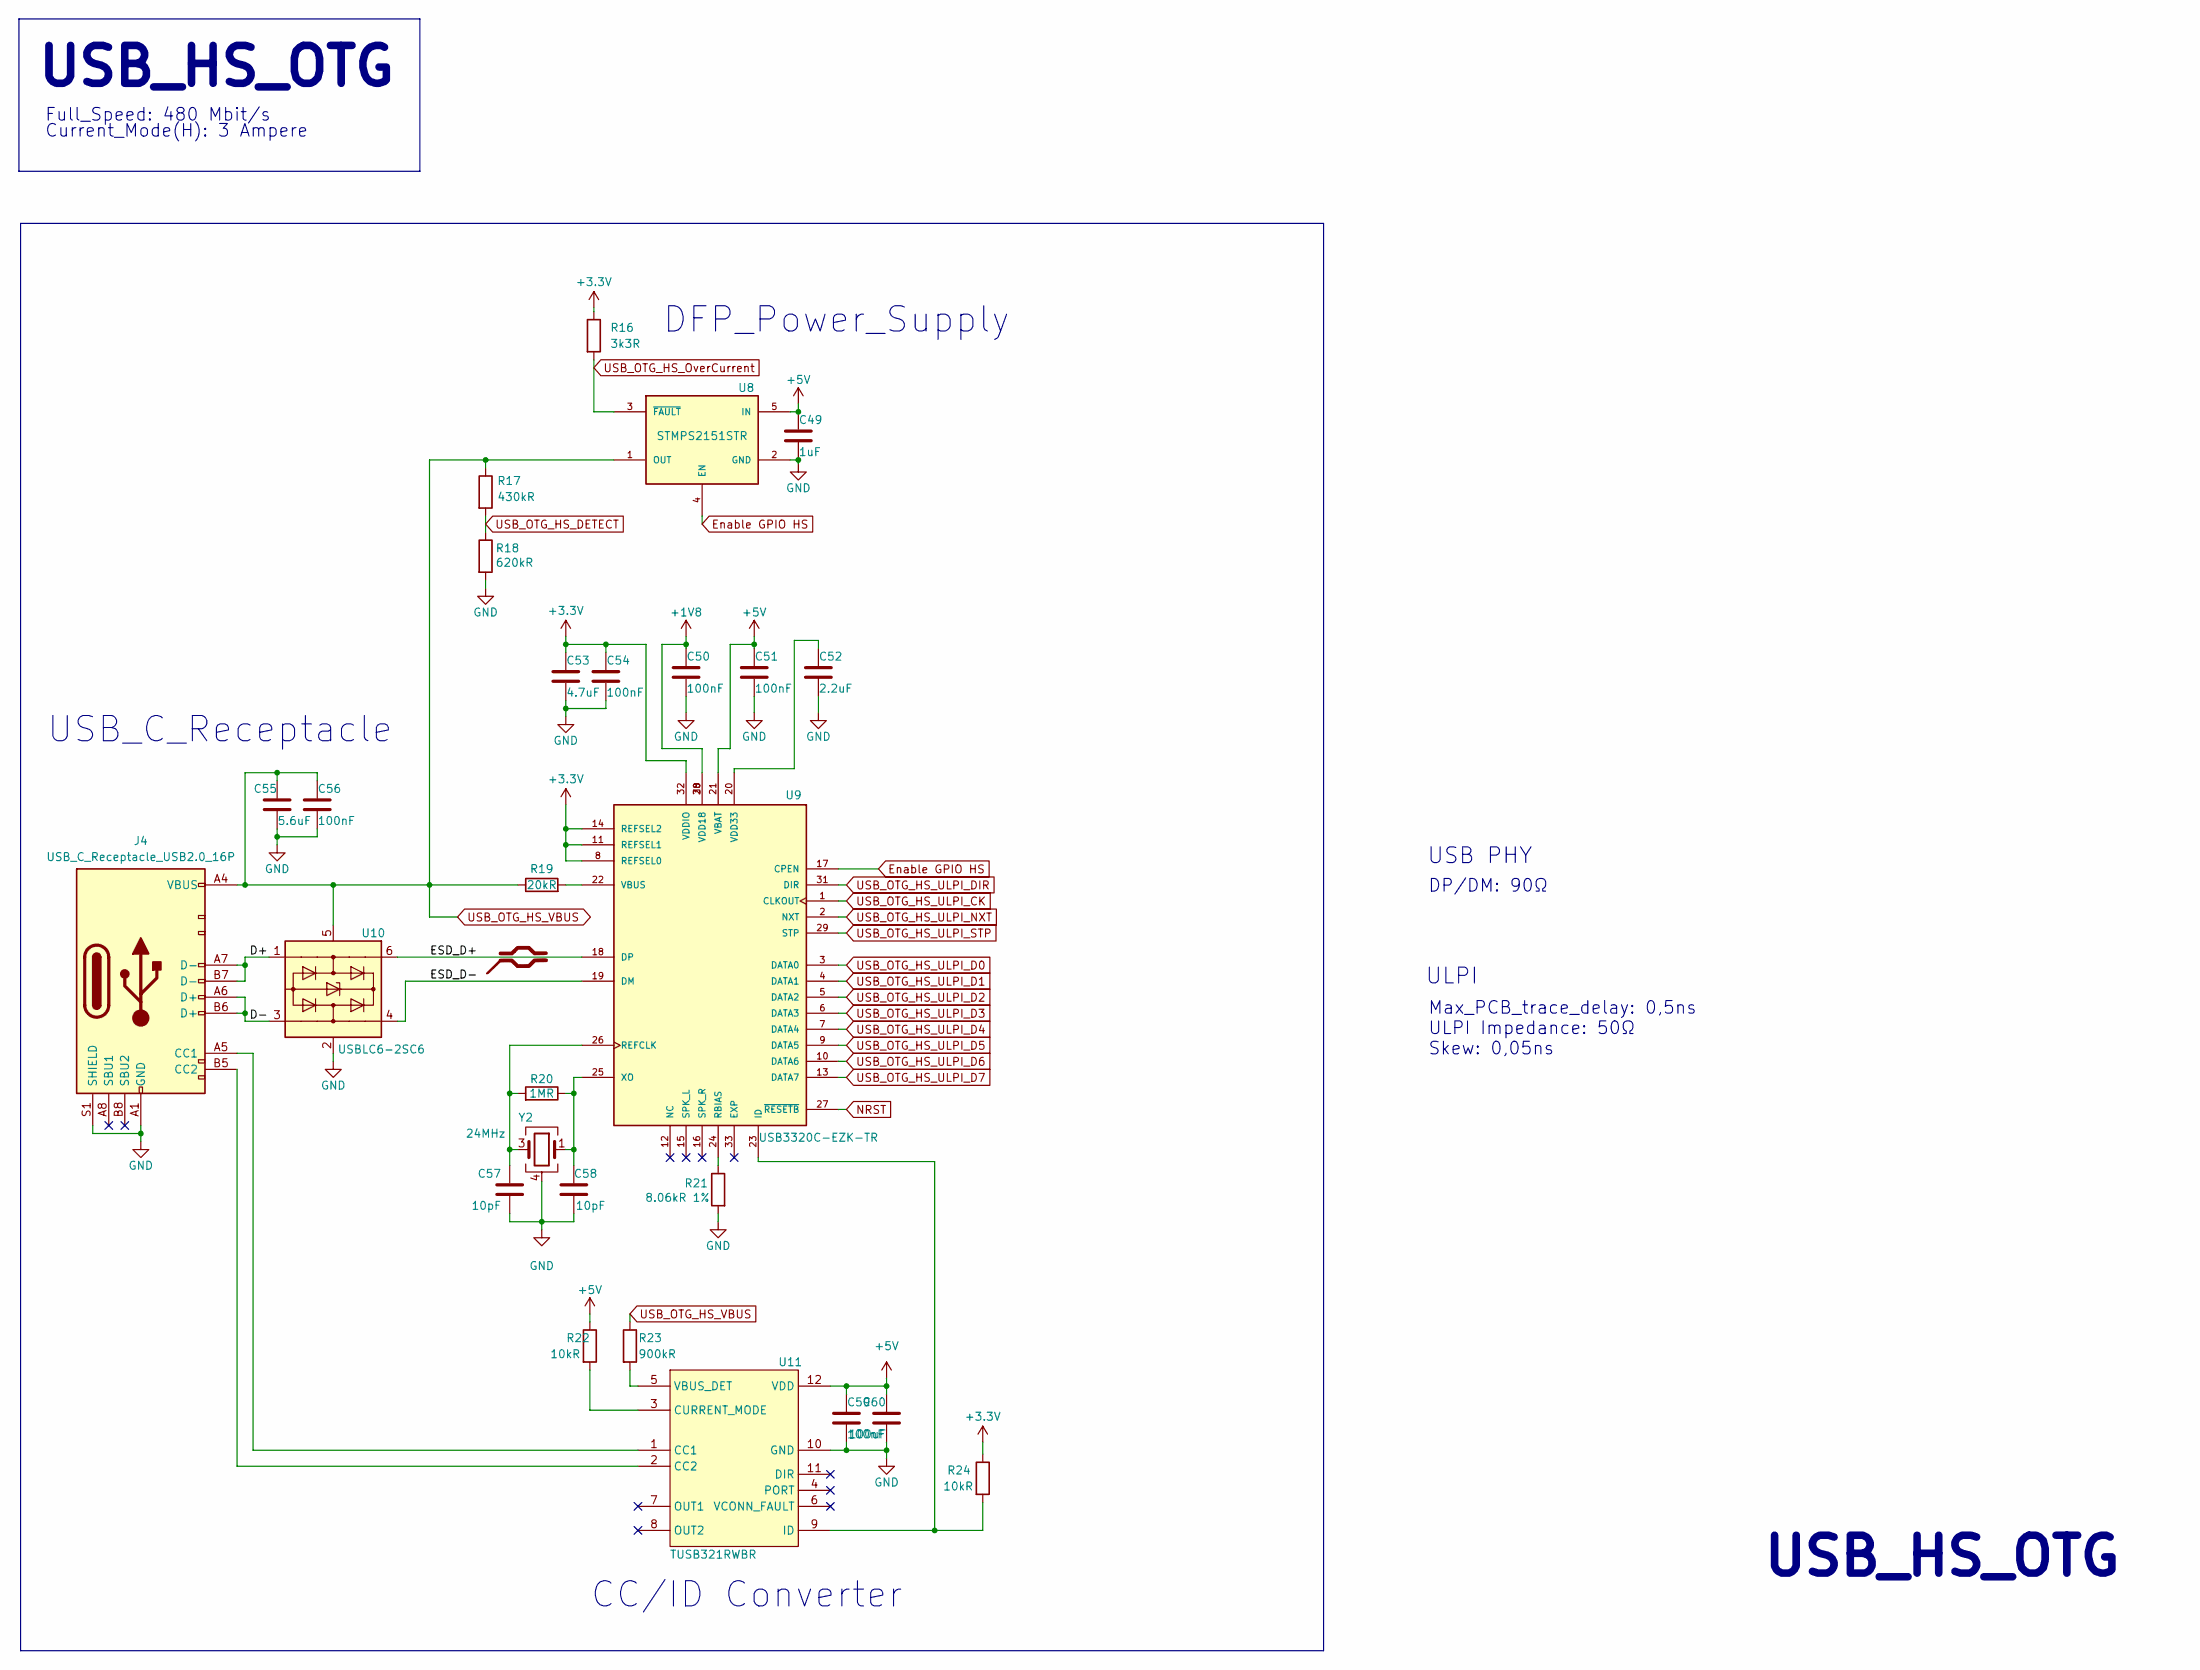
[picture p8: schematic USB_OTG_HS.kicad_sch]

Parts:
C49: 1uF; C_0603_1608Metric
C50, C51, C54, C56, C59: 100nF; C_0402_1005Metric
C52: 2.2uF; C_0402_1005Metric
C53: 4.7uF; C_0402_1005Metric
C55: 5.6uF; C_0603_1608Metric
C57, C58: 10pF; C_0402_1005Metric
C60: 100uF; C_0805_2012Metric
J4: USB_C_Receptacle_USB2.0_16P; GT-USB-7047B_JLCPCB
R16: 3k3R; R_0402_1005Metric
R17: 430kR; R_0402_1005Metric
R18: 620kR; R_0402_1005Metric
R19: 20kR; R_0402_1005Metric
R20: 1MR; R_0402_1005Metric
R21: 8.06kR 1%; R_0402_1005Metric
R22, R24: 10kR; R_0402_1005Metric
R23: 900kR; R_0402_1005Metric
U8: STMPS2151STR; STMPS; PARTREV 7
U9: USB3320C-EZK-TR; USB_ULPI
U10: USBLC6-2SC6; SOT-23-6
U11: TUSB321RWBR
Y2: 24MHz; XTAL_ECS-240-10-36-CKM-TR

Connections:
+1V8: C50.1, U9.28 (VDD18), U9.30 (VDD18); also elsewhere on the board
+5V: C49.1, C51.1, C59.1, C60.1, R22.1, U8.5 (IN), U9.21 (VBAT), U11.12 (VDD); also elsewhere on the board
/USB_OTG_HS/D+: J4.A7 (D-), J4.B7 (D-), U10.1 (I/O1)
/USB_OTG_HS/D-: J4.A6 (D+), J4.B6 (D+), U10.3 (I/O2)
/USB_OTG_HS/ESD_D+: U9.18 (DP), U10.6 (I/O1)
/USB_OTG_HS/ESD_D-: U9.19 (DM), U10.4 (I/O2)
Enable GPIO HS: U8.4 (EN), U9.17 (CPEN); also elsewhere on the board
GND: C49.2, C50.2, C51.2, C52.2, C53.2, C54.2, C55.2, C56.2, C57.2, C58.2, C59.2, C60.2, J4.A1 (GND), J4.A12 (GND), J4.B1 (GND), J4.B12 (GND), J4.S1 (SHIELD), R18.2, R21.2, U8.2 (GND), U10.2 (GND), U11.10 (GND), Y2.2, Y2.4; also elsewhere on the board
NRST: U9.27 (~RESETB); also elsewhere on the board
unnamed: J4.A5 (CC1), U11.1 (CC1)
unnamed: J4.B5 (CC2), U11.2 (CC2)
unnamed: R21.1, U9.24 (RBIAS)
unnamed: C57.1, R20.2, U9.26 (REFCLK), Y2.3
unnamed: R19.2, U9.22 (VBUS)
unnamed: C52.1, U9.20 (VDD33)
unnamed: C58.1, R20.1, U9.25 (XO), Y2.1
unnamed: R22.2, U11.3 (CURRENT_MODE)
unnamed: R24.2, U9.23 (ID), U11.9 (ID)
unnamed: R23.2, U11.5 (VBUS_DET)
USB_OTG_HS_DETECT: R17.2, R18.1; also elsewhere on the board
USB_OTG_HS_OverCurrent: R16.2, U8.3 (~FAULT); also elsewhere on the board
USB_OTG_HS_ULPI_CK: U9.1 (CLKOUT); also elsewhere on the board
USB_OTG_HS_ULPI_D0: U9.3 (DATA0); also elsewhere on the board
USB_OTG_HS_ULPI_D1: U9.4 (DATA1); also elsewhere on the board
USB_OTG_HS_ULPI_D2: U9.5 (DATA2); also elsewhere on the board
USB_OTG_HS_ULPI_D3: U9.6 (DATA3); also elsewhere on the board
USB_OTG_HS_ULPI_D4: U9.7 (DATA4); also elsewhere on the board
USB_OTG_HS_ULPI_D5: U9.9 (DATA5); also elsewhere on the board
USB_OTG_HS_ULPI_D6: U9.10 (DATA6); also elsewhere on the board
USB_OTG_HS_ULPI_D7: U9.13 (DATA7); also elsewhere on the board
USB_OTG_HS_ULPI_DIR: U9.31 (DIR); also elsewhere on the board
USB_OTG_HS_ULPI_NXT: U9.2 (NXT); also elsewhere on the board
USB_OTG_HS_ULPI_STP: U9.29 (STP); also elsewhere on the board
USB_OTG_HS_VBUS: C55.1, C56.1, J4.A4 (VBUS), J4.A9 (VBUS), J4.B4 (VBUS), J4.B9 (VBUS), R17.1, R19.1, R23.1, U8.1 (OUT), U10.5 (VBUS); also elsewhere on the board
VDDSDMMC_STM32: C53.1, C54.1, R16.1, R24.1, U9.8 (REFSEL0), U9.11 (REFSEL1), U9.14 (REFSEL2), U9.32 (VDDIO); also elsewhere on the board

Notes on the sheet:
Max_PCB_trace_delay: 0,5ns ULPI Impedance: 50Ω Skew: 0,05ns
USB_C_Receptacle
USB_HS_OTG
Current_Mode(H): 3 Ampere
Full_Speed: 480 Mbit/s
DP/DM: 90Ω
CC/ID Converter
ULPI
DFP_Power_Supply
USB PHY

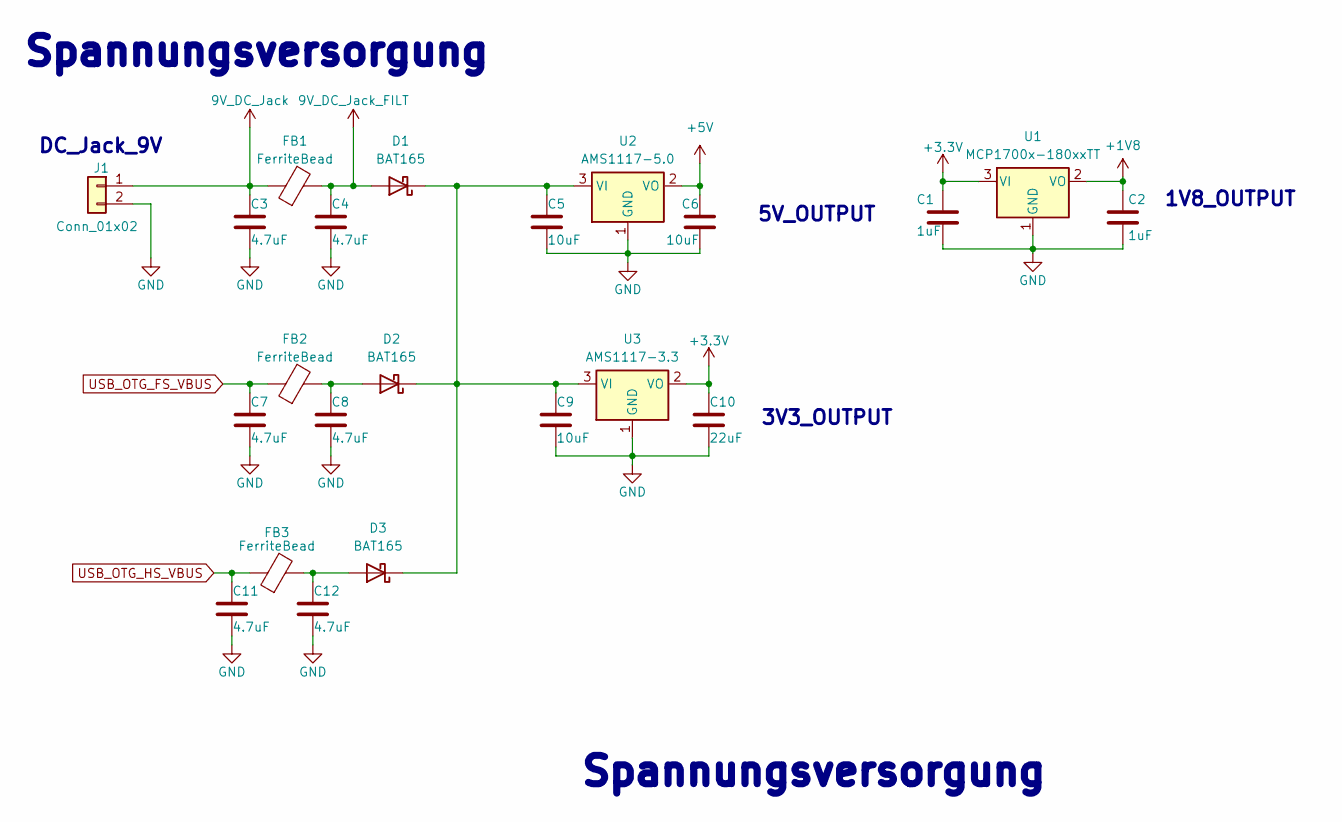
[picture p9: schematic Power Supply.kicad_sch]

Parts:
C1, C2: 1uF; C_0603_1608Metric
C3, C4, C7, C8, C11, C12: 4.7uF; C_0805_2012Metric
C5, C6, C9: 10uF; C_0805_2012Metric
C10: 22uF; C_0805_2012Metric
D1, D2, D3: BAT165
FB1, FB2, FB3: FerriteBead; L_0603_1608Metric
J1: Conn_01x02; JST_XH_B2B-XH-A_1x02_P2.50mm_Vertical
U1: MCP1700x-180xxTT; SOT-23
U2: AMS1117-5.0; SOT-223-3_TabPin2
U3: AMS1117-3.3; SOT-223-3_TabPin2

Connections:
9V_DC_Jack: C3.1, FB1.1, J1.1; also elsewhere on the board
9V_DC_Jack_FILT: C4.1, D1.2, FB1.2
+1V8: C2.1, U1.2 (VO); also elsewhere on the board
+5V: C6.1, U2.2 (VO); also elsewhere on the board
GND: C1.2, C2.2, C3.2, C4.2, C5.2, C6.2, C7.2, C8.2, C9.2, C10.2, C11.2, C12.2, J1.2, U1.1 (GND), U2.1 (GND), U3.1 (GND); also elsewhere on the board
unnamed: C8.1, D2.2, FB2.2
unnamed: C12.1, D3.2, FB3.2
unnamed: C5.1, C9.1, D1.1, D2.1, D3.1, U2.3 (VI), U3.3 (VI)
USB_OTG_FS_VBUS: C7.1, FB2.1; also elsewhere on the board
USB_OTG_HS_VBUS: C11.1, FB3.1; also elsewhere on the board
VDDSDMMC_STM32: C1.1, C10.1, U1.3 (VI), U3.2 (VO); also elsewhere on the board

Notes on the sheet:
1V8_OUTPUT
Spannungsversorgung
3V3_OUTPUT
5V_OUTPUT
DC_Jack_9V

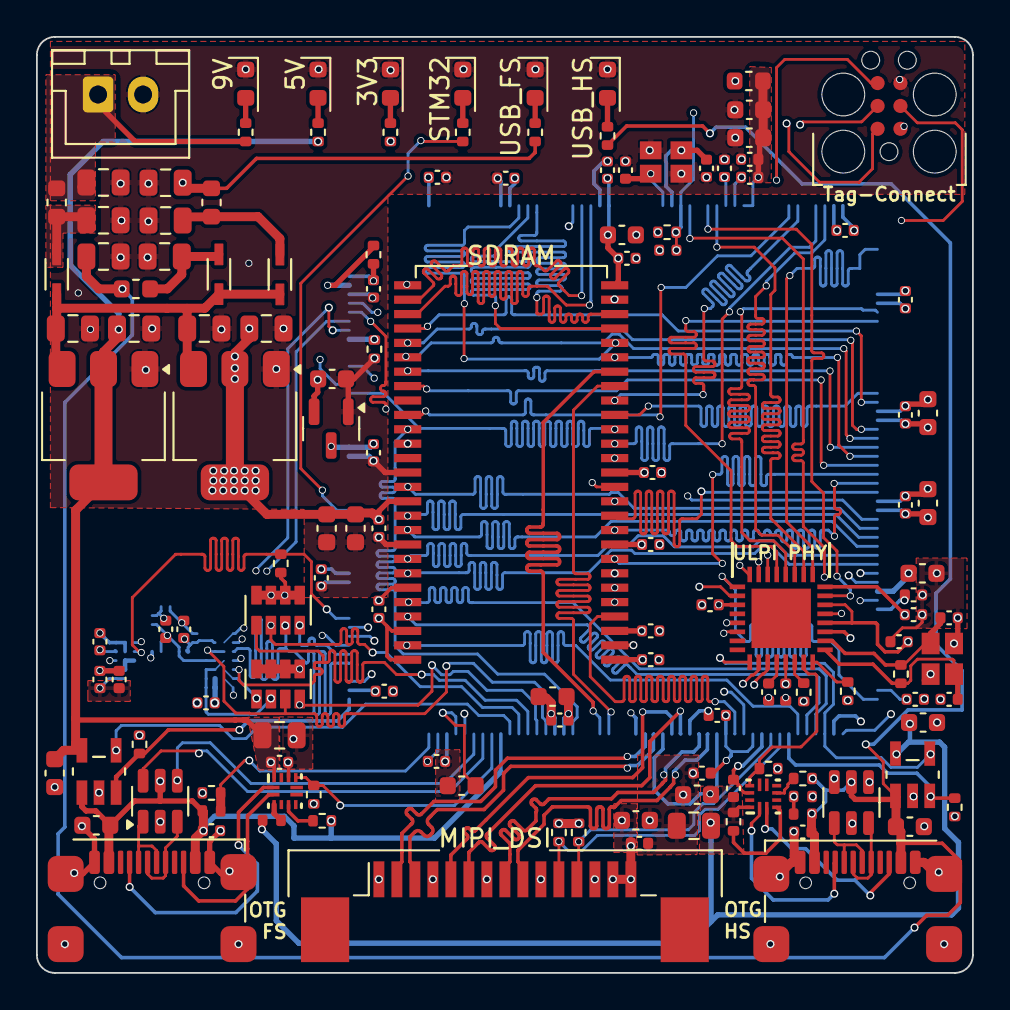
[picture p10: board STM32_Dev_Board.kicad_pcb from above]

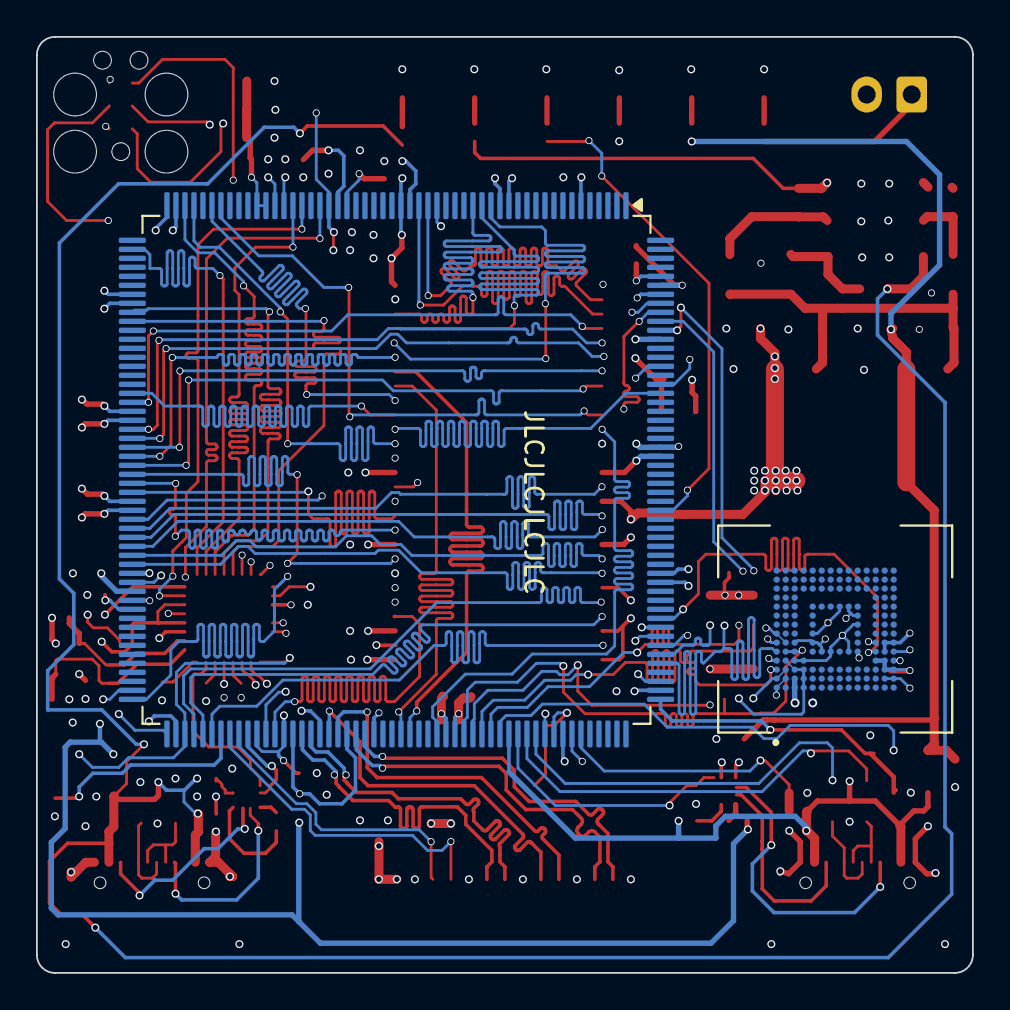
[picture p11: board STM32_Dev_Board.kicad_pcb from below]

Board: 6 copper layers, 52.0 x 52.0 mm, 139 parts (2 on the bottom side), 128 nets.
